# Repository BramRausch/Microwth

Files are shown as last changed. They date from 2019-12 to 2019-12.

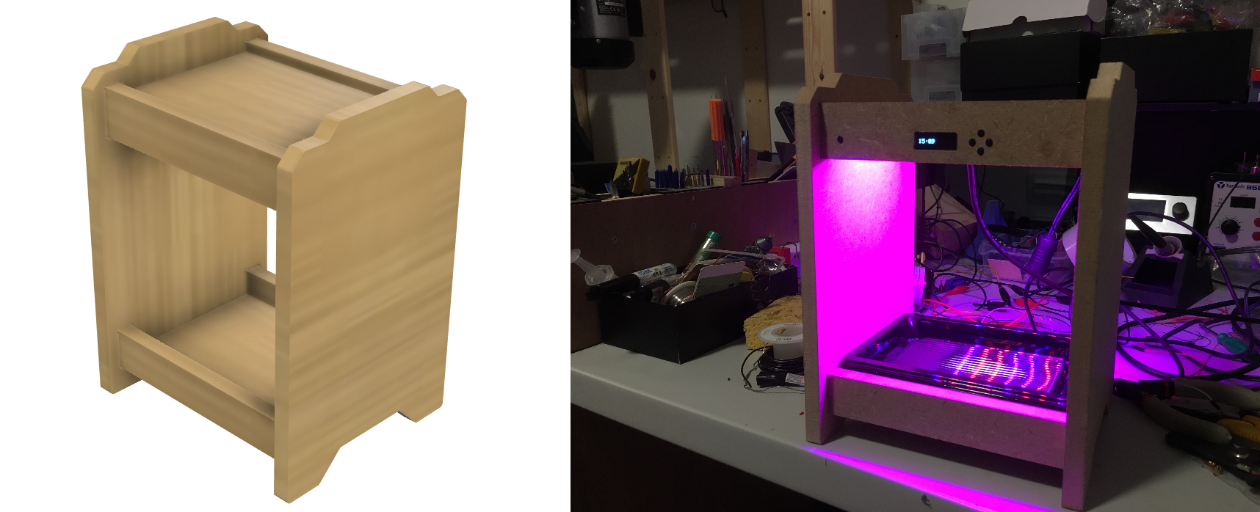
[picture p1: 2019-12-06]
Images and videos/Design V1.png

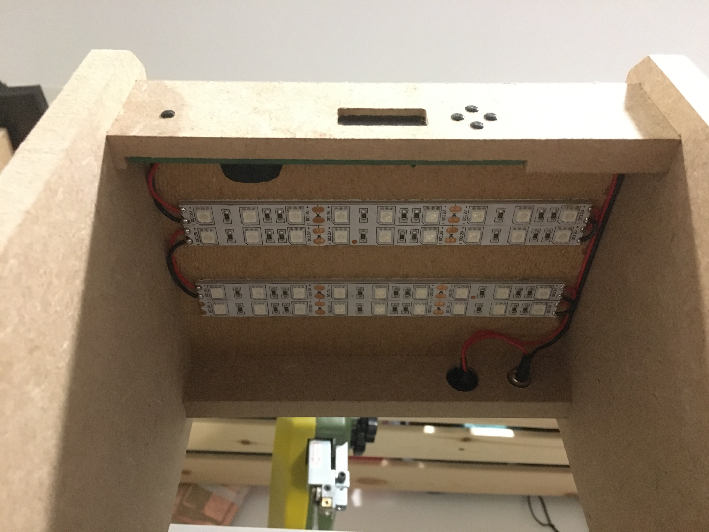
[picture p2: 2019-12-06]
Images and videos/IMG_0159.JPG

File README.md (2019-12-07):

# Microwth
The Microwth is a soilless indoor microgreen farm with build-in lighting and watering pump, the user interface provides an easy way to customize growing conditions to your liking.

The goal of this project is to create an open source platform to easily grow microgreens with a continuous harvesting cycle without too much intervention. To reach this goal I will test different lighting solutions, create multiple designs with different materials and optimize the growing cycle.

This repository hosts all hardware and software files of the platform, the current plastform runs standalone. In the future we would also like to connect the Microwth to the internet and develop a web application to manage the farms to notify the user about the grow conditions or tasks that are required.

Check out the [Hackaday.io](https://hackaday.io/project/168342-microwth-automated-microgreen-farm) page for more information and images of the build process.

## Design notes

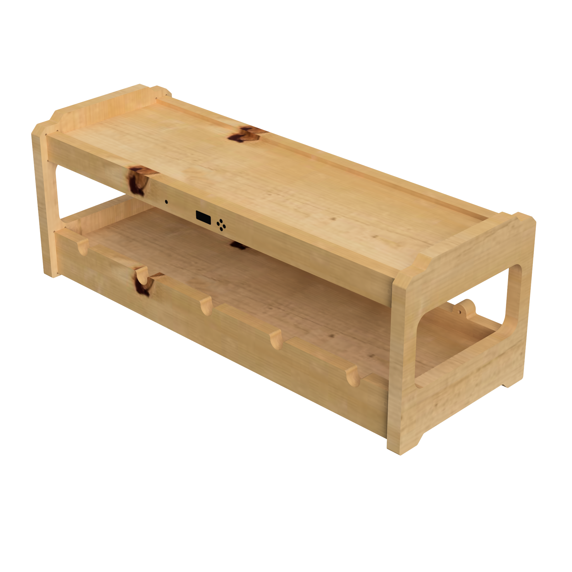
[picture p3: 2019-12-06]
Images and videos/Microwth_-_1x5_2019-Nov-07_02-55-07PM-000_CustomizedView8980378125.png

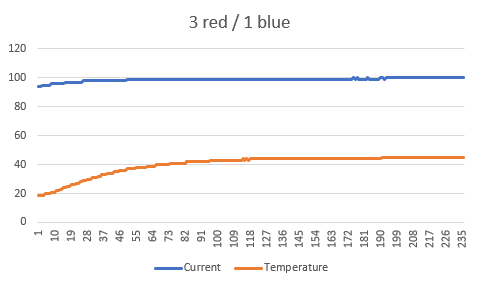
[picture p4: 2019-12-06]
Images and videos/Capture2.PNG

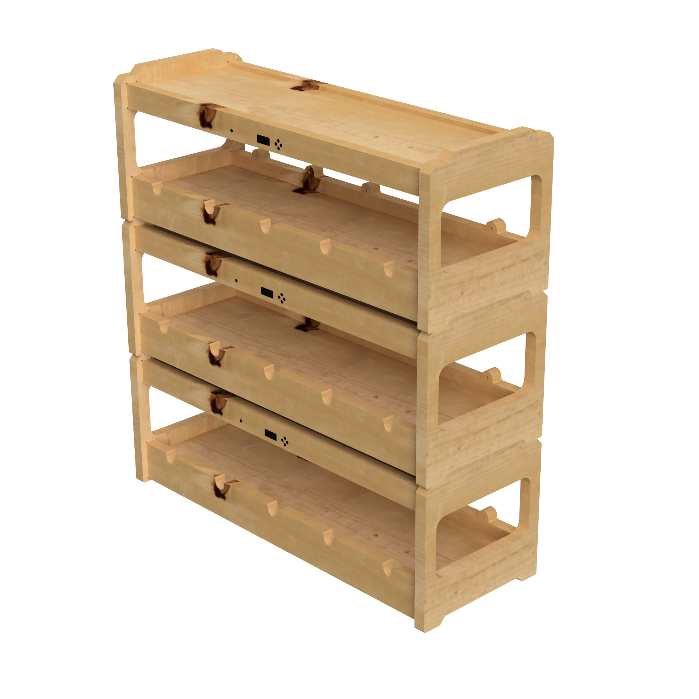
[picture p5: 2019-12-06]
Images and videos/Stack_2019-Nov-07_04-30-09PM-000_CustomizedView24084139787.png

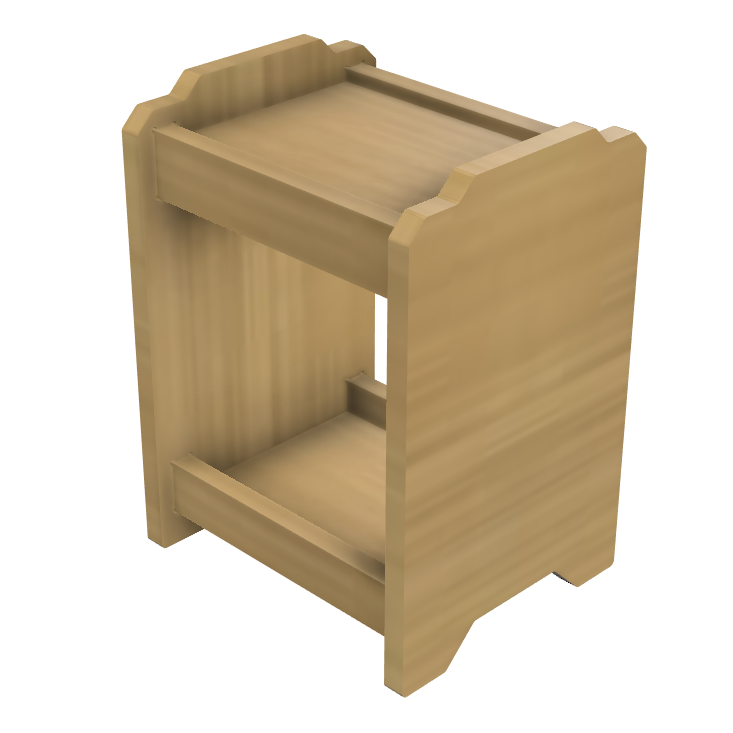
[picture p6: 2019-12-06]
Images and videos/Microwth - 1x1 v2.png

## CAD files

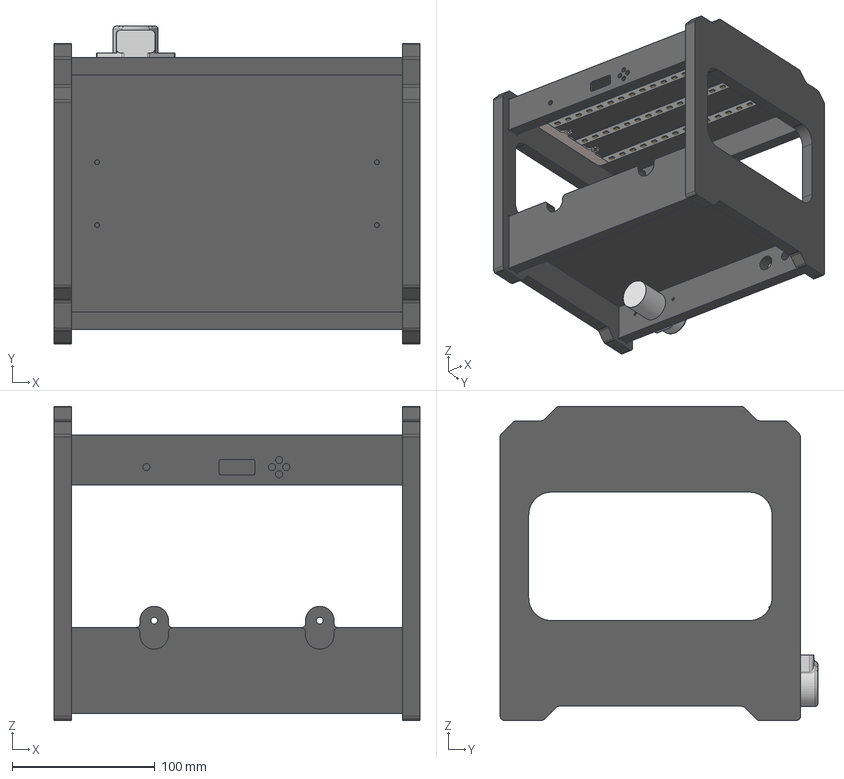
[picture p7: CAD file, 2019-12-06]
Hardware/3D drawings/Microwth (12mm).step
256.4 x 222.5 x 220.0 mm
Pump
Led strip x 3
Light connects

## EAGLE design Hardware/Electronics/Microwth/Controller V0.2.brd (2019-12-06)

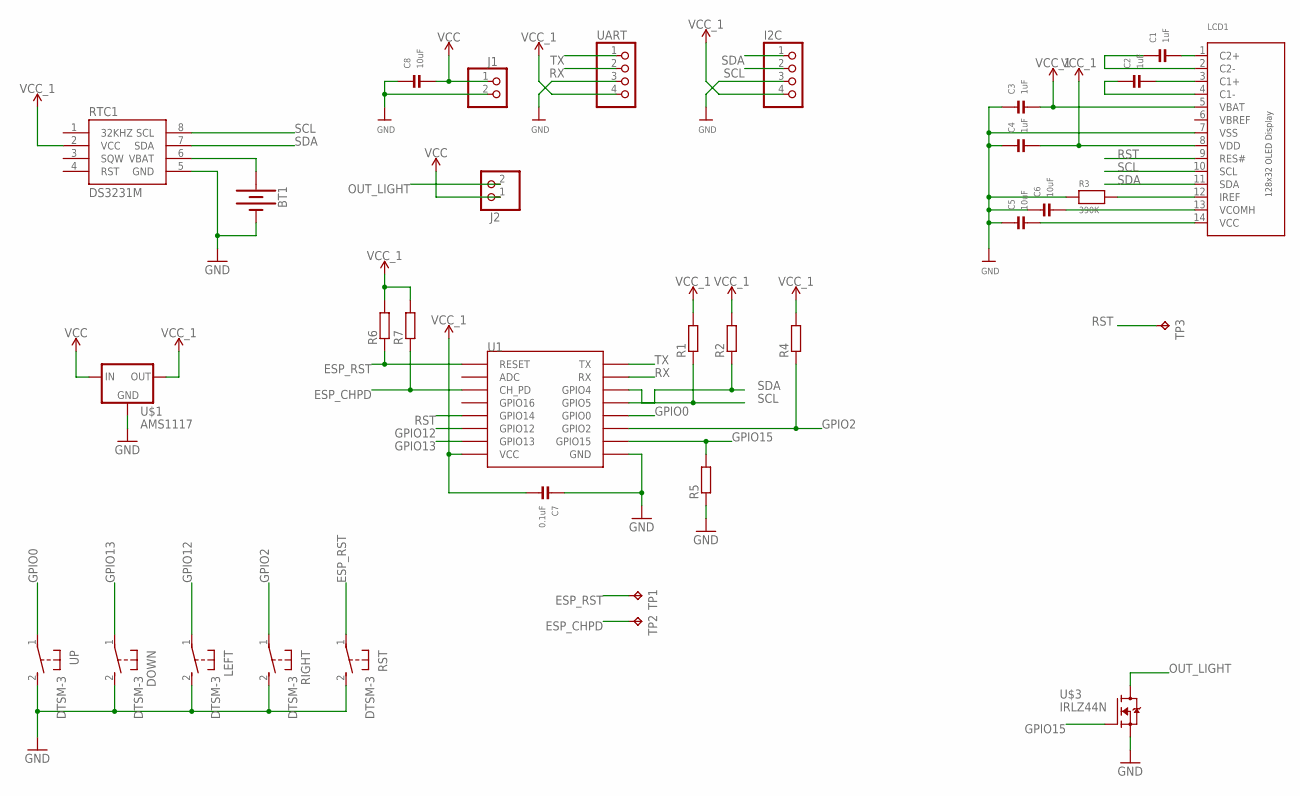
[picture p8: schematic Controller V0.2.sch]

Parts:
BT1: BATTERY-20MM_PTH; BATTCOM_20MM_PTH
C1, C2, C3, C4: 1uF; 0805
C5, C6, C8: 10uF; 0805
C7: 0.1uF; 0805
DOWN: DTSM-3
I2C: PINHD-1X4; 1X04
J1, J2: PINHD-1X2; 1X02
LCD1: DISP_OLED_UG-2832HSWEG02; UG-2832HSWEG02_WRAPUNDER
LEFT: DTSM-3
R1, R2, R4, R5, R6, R7: R-EU_R0805; R0805
R3: 390K; 0805
RIGHT: DTSM-3
RST: DTSM-3
RTC1: DS3231M; SO08
TP1, TP2, TP3: TPB1,27; B1,27
U1: ESP12SMD; ESP12-SMD
U$1: AMS1117; SOT223
U$3: IRLZ44N; TO220
UART: PINHD-1X4; 1X04
UP: DTSM-3

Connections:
ESP_CHPD: R7.1, TP2.TP, U1.CH_PD
ESP_RST: R6.1, RST.1, TP1.TP, U1.RESET
GND: BT1.2 (-), C3.1, C4.1, C5.1, C6.1, C7.1, C8.1, DOWN.2, I2C.3, J1.2, LCD1.7 (VSS), LEFT.2, R3.1, R5.1, RIGHT.2, RST.2, RTC1.5 (GND), U1.GND, U$1.1 (GND), U$3.3 (S), UART.3, UP.2
GPIO0: U1.GPIO0, UP.1
GPIO2: R4.1, RIGHT.1, U1.GPIO2
GPIO12: LEFT.1, U1.GPIO12
GPIO13: DOWN.1, U1.GPIO13
GPIO15: R5.2, U1.GPIO15, U$3.1 (G)
unnamed: C1.2, LCD1.1 (C2+)
unnamed: C1.1, LCD1.2 (C2-)
unnamed: C2.2, LCD1.3 (C1+)
unnamed: C2.1, LCD1.4 (C1-)
unnamed: C6.2, LCD1.13 (VCOMH)
unnamed: C5.2, LCD1.14 (VCC)
unnamed: LCD1.12 (IREF), R3.2
unnamed: BT1.1 (+), RTC1.6 (VBAT)
OUT_LIGHT: J2.2, U$3.2 (D)
RST: LCD1.9 (RES#), TP3.TP, U1.GPIO14
RX: U1.RXD0 (RX), UART.2
SCL: I2C.2, LCD1.10 (SCL), R1.1, RTC1.8 (SCL), U1.GPIO4
SDA: I2C.1, LCD1.11 (SDA), R2.1, RTC1.7 (SDA), U1.GPIO5
TX: U1.TXD0 (TX), UART.1
VBREF: LCD1.6 (VBREF)
VCC: C8.2, J1.1, J2.1, U$1.3 (IN)
VCC_1: C3.2, C4.2, C7.2, I2C.4, LCD1.5 (VBAT), LCD1.8 (VDD), R1.2, R2.2, R4.2, R6.2, R7.2, RTC1.2 (VCC), U1.VCC, U$1.2 (OUT), UART.4

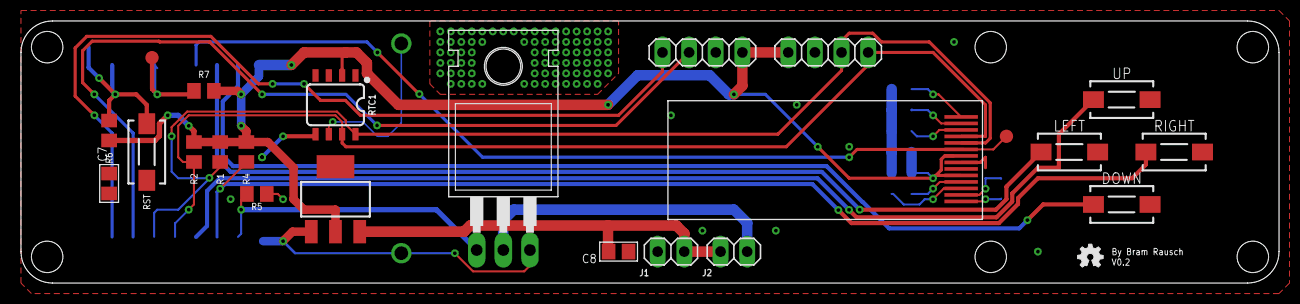
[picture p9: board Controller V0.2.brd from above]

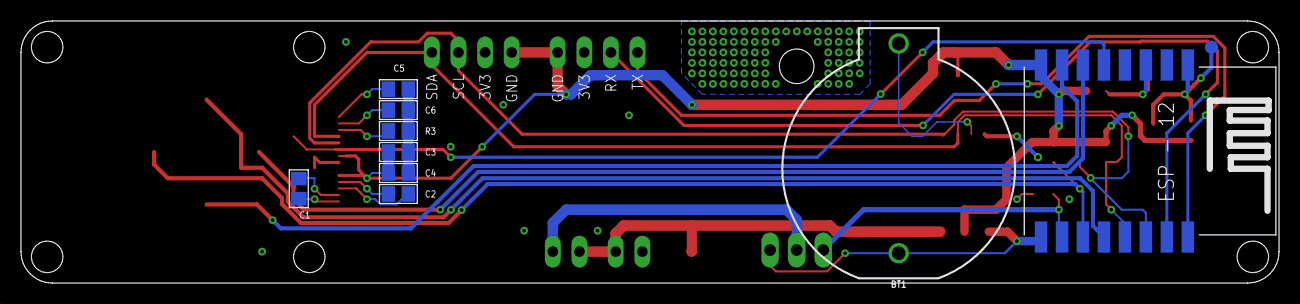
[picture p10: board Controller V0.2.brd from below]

Board: 2 copper layers, 120.0 x 25.0 mm, 34 parts (10 on the bottom side), 24 nets.

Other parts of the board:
U$4: OSHW-LOGO-MINI

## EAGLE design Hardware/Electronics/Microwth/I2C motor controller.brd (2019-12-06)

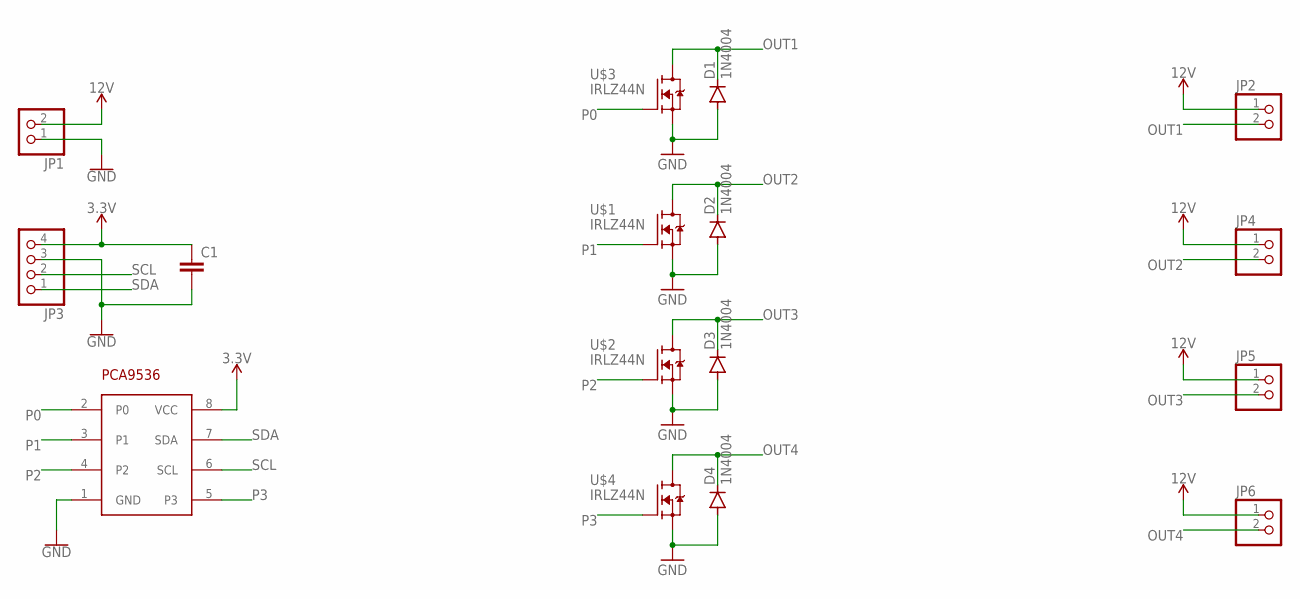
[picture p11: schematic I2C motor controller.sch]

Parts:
C1: C-EUC0805; C0805
D1, D2, D3, D4: 1N4004; DO41-10
JP1, JP2, JP4, JP5, JP6: PINHD-1X2; 1X02
JP3: PINHD-1X4; 1X04
PCA9536: PCA9536DGK; SOP65P490X110-8N
U$1, U$2, U$3, U$4: IRLZ44N; TO220

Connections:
3.3V: C1.1, JP3.4, PCA9536.8 (VCC)
12V: JP1.2, JP2.1, JP4.1, JP5.1, JP6.1
GND: C1.2, D1.A, D2.A, D3.A, D4.A, JP1.1, JP3.3, PCA9536.1 (GND), U$1.3 (S), U$2.3 (S), U$3.3 (S), U$4.3 (S)
OUT1: D1.C, JP2.2, U$3.2 (D)
OUT2: D2.C, JP4.2, U$1.2 (D)
OUT3: D3.C, JP5.2, U$2.2 (D)
OUT4: D4.C, JP6.2, U$4.2 (D)
P0: PCA9536.2 (P0), U$3.1 (G)
P1: PCA9536.3 (P1), U$1.1 (G)
P2: PCA9536.4 (P2), U$2.1 (G)
P3: PCA9536.5 (P3), U$4.1 (G)
SCL: JP3.2, PCA9536.6 (SCL)
SDA: JP3.1, PCA9536.7 (SDA)

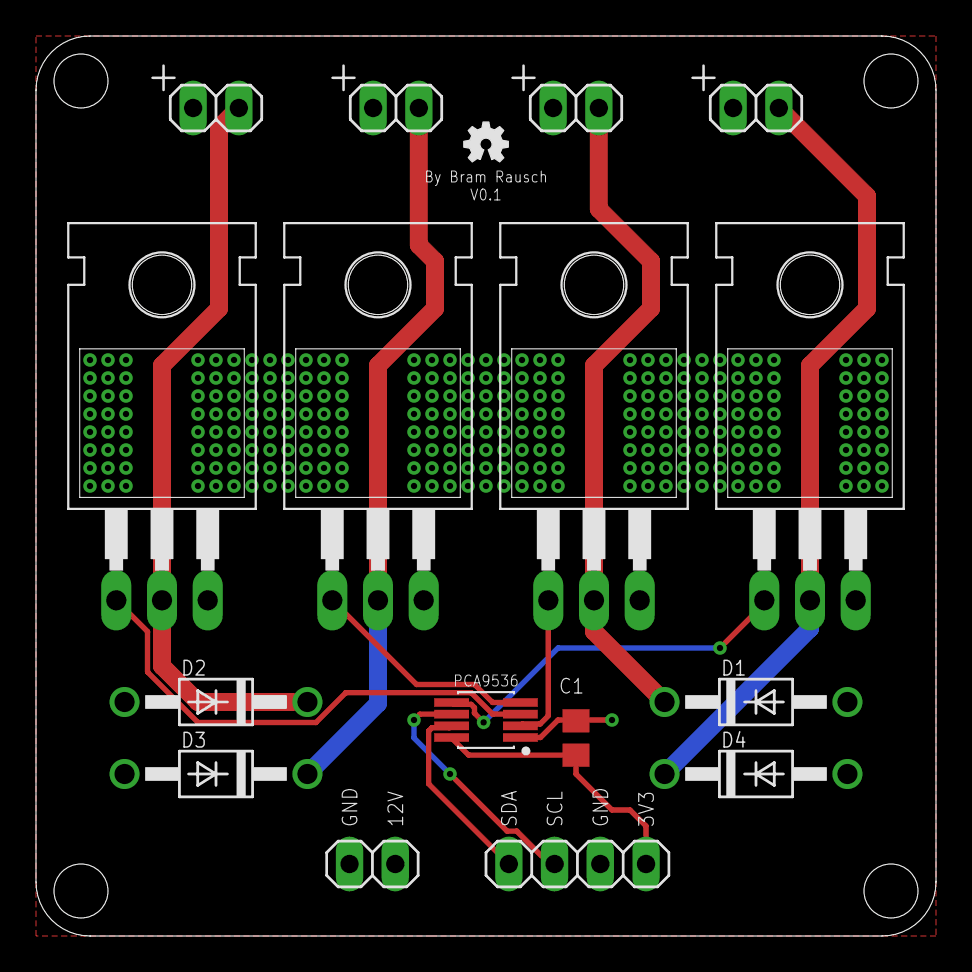
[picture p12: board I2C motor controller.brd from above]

Board: 2 copper layers, 50.0 x 50.0 mm, 17 parts (0 on the bottom side), 13 nets.

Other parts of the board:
U$5: OSHW-LOGO-MINI

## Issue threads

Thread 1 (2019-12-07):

Add label to "Start grow" settings

BramRausch, 2019-12-07:
The "start grow" button walks you through a couple of different settings. These currently aren't labeled so it is unclear which settings does what if you don't know the system.

The following order is used:

1.  Light on time (step 220)
2.  Light off time (step 230)
3.  Pump interval (step 240)
4.  Pumping duration (step 250)

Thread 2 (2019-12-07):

Manual pump on

BramRausch, 2019-12-07:
The "Pump" menu item should toggle the pump on and off to be able to manually water plants and to ensure water flows through the tubing, this menu item can be found in step 40.

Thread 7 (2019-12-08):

Controller PCB V0.3 update

BramRausch, 2019-12-08:
- [ ] Add bypass capacitors next to each IC
- [ ] Fix silk screen (Reverse 3V and GND next to the headers)
- [ ] Fix button footprint
- [ ] ?Change header locations
- [ ] ?Create design with [ublox NINA-W102](https://www.u-blox.com/sites/default/files/NINA-W10_DataSheet_%28UBX-17065507%29.pdf)

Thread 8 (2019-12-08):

Pump controller PCB V0.2 update

BramRausch, 2019-12-08:
- [ ] Add pull down resistor to the gate pin
- [ ] Separate vias underneath the MOSFET from ground
- [ ] Enlarge power in holes to support the power of multiple pumps

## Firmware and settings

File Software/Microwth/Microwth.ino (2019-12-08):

#include <Wire.h>
#include <EEPROM.h>
#include <Adafruit_GFX.h>
#include <Adafruit_Sensor.h>
#include <Adafruit_BME280.h>
#include <Adafruit_SSD1306.h>

#define UP 0
#define DOWN 13
#define LEFT 12
#define RIGHT 2
#define LIGHTS 15
#define OLED_RESET 14

#define SCREEN_WIDTH 128 // OLED display width, in pixels
#define SCREEN_HEIGHT 32 // OLED display height, in pixels
Adafruit_SSD1306 display(SCREEN_WIDTH, SCREEN_HEIGHT, &Wire, OLED_RESET);

Adafruit_BME280 bme;

const byte buttonPin[] = {UP,DOWN,LEFT,RIGHT}; // Array of button pins
byte hour, minute, second;  // Current time
int hrs, mins;  // Variables to seperate the current time from the new settings
unsigned long selectTime =  0;
unsigned long timer1 =  0;
int select = 0;
int steps = 0;
byte setStep = 0;
bool toggle = 0;
int lightOn = 0;
int lightOff = 0;
int currentTime = 0;
float humidity;
float temp;
int pumpInt = 0;
byte pumpTime;
int pumpSet;

void setup() {
  Serial.begin(9600);

  // Initialize IO
  Wire.begin(4, 5);
  for (byte i=0; i<sizeof(buttonPin); i++) pinMode(buttonPin[i], INPUT_PULLUP);
  pinMode(LIGHTS, OUTPUT);
  digitalWrite(LIGHTS, 0);

  beginMotorController();
  // writeMotorController(0b0001);

  // Retrieve settings from EEPROM
  EEPROM.begin(9);
  lightOn = EEPROM.read(0)*60+EEPROM.read(1);
  lightOff = EEPROM.read(2)*60+EEPROM.read(3);
  pumpInt = EEPROM.read(4)*60+EEPROM.read(5);  // Pump interval
  pumpTime = EEPROM.read(6);  // Pump amount
  pumpSet = EEPROM.read(7)*60+EEPROM.read(8);  // Time when the grow was started

  // Initialize display
  if(!display.begin(SSD1306_SWITCHCAPVCC, 0x3C)) { // Address 0x3C for 128x32
    Serial.println(F("SSD1306 allocation failed"));
    for(;;); // Don't proceed, loop forever
  }
  display.display();
  display.clearDisplay();

  // Initialize BME280
  bme.begin();
  humidity = bme.readHumidity();
  temp = bme.readTemperature();
    
  // Initialize clock
  initClock();
  readClockTime();
  currentTime = hour*60+minute;
  checkTriggers();
}

void loop() {
  currentTime = hour*60+minute;
  checkTriggers();
  
  switch(select){
    case 0:  // display time
      readClockTime();
      displayTime(hour, minute);

      // Menu navigation options
      if (button(0, 0)) select = 30;  // up
      if (button(1, 0)) select = 10;  // down
    break;
    case 10:  // display sensor data
      humidity = bme.readHumidity();
      temp = bme.readTemperature();
      displayBME280(temp, humidity);
      
      // Menu navigation options
      if (button(0, 0)) select = 0;  // up
      if (button(1, 0)) select = 20;  // down
    break;
    case 20:  // Set time option text
      displayText("Set time", 2);

      // Menu navigation options
      if (button(0, 0)) select = 10;  // up
      if (button(1, 0)) select = 30;  // down
      if (button(3, 0)) select = 210;  // right
    break;
    case 30:  // Start grow option text
      displayText("Start grow", 2);

      // Menu navigation options
      if (button(0, 0)) select = 20;  // up
      if (button(1, 0)) select = 40;  // down
      if (button(3, 0)) select = 220;  // right
    break;
    case 40:  // Start grow option text
      displayText("Pump ", 2);

      // Menu navigation options
      if (button(0, 0)) select = 30;  // up
      if (button(1, 0)) select = 0;  // down
      if (button(3, 1)){
        toggle = !toggle;
      }
    break;
    case 210:  // set time
      hrs = hour;
      mins = minute;
      if (setStep == 0){
        setHour(button(0, 1) - button(1, 1));
        hour = hrs;
        displayBinkingTime(hour, minute, 0);

        // Menu navigation options
        if (button(2, 0)) select = 20;  // left
        if (button(3, 0)) setStep = 1;  // right
      } else if(setStep == 1){
        setMinute(button(0, 1) - button(1, 1));
        minute = mins;
        displayBinkingTime(hour, minute, 1);

        // Menu navigation options
        if (button(2, 0)) setStep = 0;  // left
        if (button(3, 0)) {  // right
          second = 0;
          setClockTime();
          setStep = 0;
          select = 0;  
        }
      }
    break;
    case 220:  // Setting lights on
      hrs = lightOn/60%24;
      mins = lightOn%60;
      if (setStep == 0){
        setHour(button(0, 1) - button(1, 1));
        lightOn = hrs*60+mins;
        displayBinkingTime(hrs, mins, 0);

        // Menu navigation options
        // if (button(2, 0)) select = 0;  // left can't go back
        if (button(3, 0)) setStep = 1;  // right
      } else if(setStep == 1){
        setMinute(button(0, 1) - button(1, 1));
        lightOn = hrs*60+mins;
        EEPROM.write(0, hrs);
        EEPROM.write(1, mins);
        EEPROM.commit();
        displayBinkingTime(hrs, mins, 1);

        // Menu navigation options
        if (button(2, 0)) setStep = 0;  // left
        if (button(3, 0)) {  // right
          setStep = 0;
          select = 230;  
        }
      }
    break;
    case 230:  // Setting lights off
      hrs = lightOff/60%24;
      mins = lightOff%60;
      if (setStep == 0){
        setHour(button(0, 1) - button(1, 1));
        lightOff = hrs*60+mins;
        displayBinkingTime(hrs, mins, 0);

        // Menu navigation options
        if (button(2, 0)) select = 220;  // left
        if (button(3, 0)) setStep = 1;  // right
      } else if(setStep == 1){
        setMinute(button(0, 1) - button(1, 1));
        lightOff = hrs*60+mins;
        
        displayBinkingTime(hrs, mins, 1);

        // Menu navigation options
        if (button(2, 0)) setStep = 0;  // left
        if (button(3, 0)) {  // right
          setStep = 0;
          select = 240;  

          // Only write EEPROM when ready
          EEPROM.write(2, hrs);
          EEPROM.write(3, mins);
          EEPROM.commit();
        }
      }
    break;
    case 240:  // Setting pump interval
      hrs = pumpInt/60%24;
      mins = pumpInt%60;
      if (setStep == 0){
        setHour(button(0, 1) - button(1, 1));
        displayBinkingTime(hrs, mins, 0);
        pumpInt = hrs*60+mins;

        // Menu navigation options
        if (button(2, 0)) select = 230;  // left
        if (button(3, 0)) setStep = 1;  // right
      } else if(setStep == 1){
        setMinute(button(0, 1) - button(1, 1));
        displayBinkingTime(hrs, mins, 1);
        pumpInt = hrs*60+mins;

        // Menu navigation options
        if (button(2, 0)) setStep = 0;  // left
        if (button(3, 0)) {  // right
          pumpInt = hrs*60+mins;
          
          setStep = 0;
          select = 250;  

          // Only write EEPROM when ready
          EEPROM.write(4, hrs);
          EEPROM.write(5, mins);
          EEPROM.commit();
        }
      }
    break;
    case 250:  // Setting pump time
      pumpTime = (pumpTime + button(0, 1) - button(1, 1));

      String con = String(String(pumpTime, DEC) + " s");
      displayText(con, 2);

      if (button(2, 0)) select = 240;  // left
      if (button(3, 0)) {
        select = 0;  // right
        EEPROM.write(6, pumpTime);

        // Store current time
        pumpSet = currentTime;
        EEPROM.write(7, hour);
        EEPROM.write(8, minute);
        EEPROM.commit();
      }
    break;
  }
}

void setHour(int steps){
  if (steps == 1) {
    if (hrs == 23) {
      hrs = 0;
    } else{
      hrs++;
    }
  }
  if (steps == -1) {
    if (hrs == 0) {
      hrs = 23;
    } else{
      hrs--;
    }
  }
}

void setMinute(int steps){
  if (steps == 1) {
    if (mins == 59) {
      mins = 0;
    } else{
      mins++;
    }
  }
  if (steps == -1) {
    if (mins == 0) {
      mins = 59;
    } else{
      mins--;
    }
  }
}

void checkTriggers(){
  // Check light trigger time
  if (lightOn > lightOff){  // Light switch condition when the switch on time is larger then the light off time
    if ((currentTime >= lightOn && currentTime <= 1440) || (currentTime < lightOff && currentTime > 0)){
      digitalWrite(LIGHTS, HIGH);
    } else {
      digitalWrite(LIGHTS, LOW);
    }
  } else if(lightOn < lightOff){  // Light switch condition when the switch on time is smaller then the light off time
    if (currentTime >= lightOn && currentTime < lightOff){
      digitalWrite(LIGHTS, HIGH);
    } else {
      digitalWrite(LIGHTS, LOW);
    }
  } else if(lightOn == lightOff){  // Keep the light on when the on and off time are equal
    digitalWrite(LIGHTS, HIGH);
  }
 
  // Variables to keep track of the pump
  static bool pumpOn;
  static unsigned long int pumpTimer1;
  static unsigned long int onTime;

  // change to : currentime-settime%interval
  if ((currentTime - pumpSet) % pumpInt == 0 && onTime != currentTime && !pumpOn) {  // When an interval is reached from the time the interval has been set
    // turn pump on
    pumpOn = 1;
    pumpTimer1 = millis();
    onTime = currentTime;
    writeMotorController(0b1111);
  } else if (pumpOn && millis()-pumpTimer1 >= pumpTime*1000) {  // If the pump has been on the set ammount off time
    // turn pump off
    writeMotorController(0b0);
    pumpOn = 0;
  }
}

boolean button(byte k, boolean repeatFlg) { 
  const unsigned long debounce  =   50;
  const unsigned long interval1 =  500;
  const unsigned long interval2 =  100;

  static unsigned long buttonTime[sizeof(buttonPin)];
  static boolean       buttonFlg[sizeof(buttonPin)];
  static unsigned long repeatTime[sizeof(buttonPin)];
  static unsigned long interval[sizeof(buttonPin)];

  if (!digitalRead(buttonPin[k])) {      
    buttonTime[k]=millis();
    if (!buttonFlg[k]) {
      buttonFlg[k]=1;
      repeatTime[k]=millis();
      return(1);
    }
    if (repeatFlg && ((millis()-repeatTime[k])>interval[k])) {
      buttonFlg[k]=0;    
      interval[k]=interval2; 
    }
  }
  else {
    if ((millis()-buttonTime[k])>debounce) {
      buttonFlg[k]=0;
      interval[k]=interval1; 
    }
  }
  return(0);
}

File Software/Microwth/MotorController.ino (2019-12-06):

bool beginMotorController(){
    Wire.beginTransmission(0x41);  // Select PCA9536
    Wire.write(0x01);  // Select output registry
    Wire.write(0xF0);  // configure all output as LOW
    Wire.endTransmission(); 

    Wire.beginTransmission(0x41);  // Select PCA9536
    Wire.write(0x03);  // Select control registry
    Wire.write(0xF0);  // set all pins to output
    return Wire.endTransmission();   
}

bool writeMotorController(byte output){
    Wire.beginTransmission(0x41);  // Select PCA9536
    Wire.write(0x01);  // Select output registry
    Wire.write(0xF0 | output);  // set 
    return Wire.endTransmission(); 
}

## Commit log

2019-11-16 V0.2
    * changed menu structure
    * added grow mode (set pump interval, pump duration, light on time and light off time)
    * improved comments
    * centered text
2019-12-06 new file: Microwth/DS3231.ino new file: Microwth/Display.ino modified: Microwth/Microwth.ino new file: Microwth/MotorController.ino V0.3 Setting up proper version control
2019-12-06 Added hardware and imagary
    [Light comparison.xlsx, Microwth (12mm).step]
2019-12-06 Added eagle files
    [Controller V0.1.brd, Controller V0.1.sch, Controller V0.2.brd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]
2019-12-08 bug fix unable to set motor interval
    [Microwth.ino]

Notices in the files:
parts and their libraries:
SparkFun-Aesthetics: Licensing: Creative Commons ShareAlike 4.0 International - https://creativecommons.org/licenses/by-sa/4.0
